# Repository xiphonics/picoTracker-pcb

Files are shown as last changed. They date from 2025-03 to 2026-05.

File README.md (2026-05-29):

# PCB for PicoTracker
All data in order to fabricate the PCB for the [picoTracker](https://github.com/xiphonics/picoTracker)

Buy the official kit at [xiphonics store](https://xiphonics.com/products/picotracker-pcb-kit)
# Trademark Notice

This repository contains the open-source hardware design files for the picoTracker project.

The hardware design files are released under the CC0 1.0 Universal license and may be used, modified, manufactured, and sold without restriction.

However, the **picoTracker** name, logos, product branding, and associated trademarks are **not** covered by the CC0 license and are not licensed for use by third parties.

You may manufacture and sell hardware derived from these design files, but you may not market, advertise, label, or otherwise represent such products using the "picoTracker" name or branding without prior written permission from Xiphonics.

Products manufactured from these files must be sold under a different product name and must not imply endorsement by, affiliation with, or origin from Xiphonics.

To facilitate this separation, the manufacturing files distributed through this repository intentionally omit picoTracker branding elements.

Use of the picoTracker name in connection with unauthorized derivative hardware may constitute trademark infringement and unfair competition.

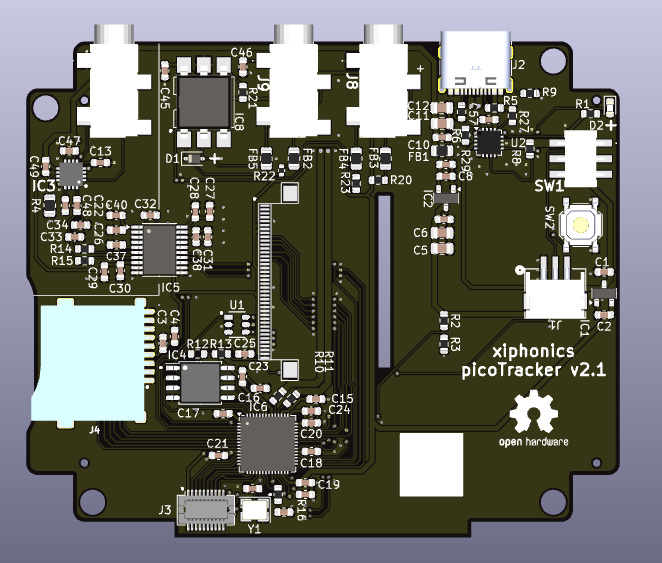
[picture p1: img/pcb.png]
picoTrakerPCB


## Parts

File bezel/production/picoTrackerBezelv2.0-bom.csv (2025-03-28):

Designator | Footprint | Quantity | Value | LCSC Part #
H1, H2, H3, H4 | MountingHole_3.2mm_M3 | 4 | MountingHole

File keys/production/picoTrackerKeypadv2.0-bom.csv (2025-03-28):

Designator | Footprint | Quantity | Value | LCSC Part #
H1, H2, H3 | MountingHole_3.2mm_M3 | 3 | MountingHole
J1 | Hirose_DF12_DF12E3.0-20DP-0.5V_2x10_P0.50mm_Vertical | 1 | DF12NC(5.0)-20DP-0.5V(51) | C3650665
SW10 | Cherry-MX-Low-Profile-kailh | 1 | NAV | C400229
SW11 | Cherry-MX-Low-Profile-kailh | 1 | PLAY | C400229
SW3 | Cherry-MX-Low-Profile-kailh | 1 | LEFT | C400229
SW4 | Cherry-MX-Low-Profile-kailh | 1 | DOWN | C400229
SW5 | Cherry-MX-Low-Profile-kailh | 1 | RIGHT | C400229
SW6 | Cherry-MX-Low-Profile-kailh | 1 | UP | C400229
SW7 | Cherry-MX-Low-Profile-kailh | 1 | ALT | C400229
SW8 | Cherry-MX-Low-Profile-kailh | 1 | EDIT | C400229
SW9 | Cherry-MX-Low-Profile-kailh | 1 | ENTER | C400229

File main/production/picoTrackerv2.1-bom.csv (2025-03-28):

Designator | Footprint | Quantity | Value | LCSC Part #
C1, C2, C27, C29, C3, C31, C40 | 0603 | 7 | 10uF | C19702
C10, C22, C32, C37, C48, C7, C8, C9 | 0603 | 8 | 2.2uF | C23630
C11, C12, C5, C6 | 0805 | 4 | 47uF | C16780
C13, C23, C24, C47, C49, C57 | 0603 | 6 | 1uF | C15849
C14, C15, C16, C17, C18, C19, C20, C21, C25, C26, C28, C30, C38, C4, C45, C46 | 0603 | 16 | 100nF | C14663
C33, C34 | 0603 | 2 | 2.2nF | C1604
C35, C36 | 0603 | 2 | 20pF | C1648
D1 | D_SOD-323 | 1 | 1N4148WS | C2128
D2 | 0603 | 1 | LED | C2286
FB1, FB2, FB3, FB4, FB5 | 0805 | 5 | 600@100MHz | C1017
H1, H2, H3, H4 | MountingHole_3.2mm_M3 | 4 | MountingHole
IC1, IC2 | SOT-23 | 2 | XC6206P332MR | C5446
IC3 | QFN50P300X300X100-17N-D | 1 | TPA6139A2RGTR | C2868391
IC4 | SOIC-8_5.23x5.23mm_P1.27mm | 1 | W25Q128JVS | C97521
IC5 | TSSOP-20_4.4x6.5mm_P0.65mm | 1 | PCM5102A | C107671
IC6 | QFN-56-1EP_7x7mm_P0.4mm_EP3.2x3.2mm | 1 | RP2040 | C2040
IC8 | SMDIP-6_W9.53mm | 1 | H11L1 | C78589
J1 | CONN_S3B-ZR-SM4A-TFLFSN_JST | 1 | Conn_01x03 | C72591
J10 | FPC_40-flap | 1 | FPC-05FB-40PH20 | C2856837
J2 | USB_C_Receptacle_G-Switch_GT-USB-7010ASV | 1 | USB_C_Receptacle_USB2.0 | C2988369
J3 | Hirose_DF12_DF12C3.0-20DS-0.5V_2x10_P0.50mm_Vertical | 1 | Conn_02x10_Counter_Clockwise | C3645324
J4 | Xunpu_TF-115_microSD | 1 | Micro_SD_Card | C720505
J5 | PJ327C4A | 1 | Headphones | C145813
J8 | PJ327C4A | 1 | MIDI Out | C145813
J9 | PJ327C4A | 1 | MIDI In | C145813
R1, R13, R16, R27, R8 | 0603 | 5 | 1k | C21190
R10, R11 | 0603 | 2 | 27 | C25190
R12 | 0603 | 1 | DNF
R14, R15 | 0603 | 2 | 470 | C23179
R2, R3 | 0603 | 2 | 100k | C25803
R20 | 0603 | 1 | 33 | C23140
R21 | 0603 | 1 | 270 | C22966
R22 | 0402 | 1 | 220 | C1111
R23 | 0603 | 1 | 10 | C22859
R29 | 0603 | 1 | 560 | C23204
R4 | 0805 | 1 | 82k | C17840
R5, R6 | 0603 | 2 | 5k1 | C23186
R9 | 0603 | 1 | 1M | C22935
SW1 | MS22D28G020 | 1 | MS-22D28-G020 | C963205
SW2 | SW_Push_1P1T_XKB_TS-1187A | 1 | SW_SPST | C318884
U1 | SOT23-6_DIO | 1 | AP2502KTR-G1 | C460349
U2 | VQFN-16-1EP_3x3mm_P0.5mm_EP1.6x1.6mm | 1 | BQ24074RGT | C54313
Y1 | Crystal_SMD_3225-4Pin_3.2x2.5mm | 1 | 12MHz 20pF ±10ppm | C9002

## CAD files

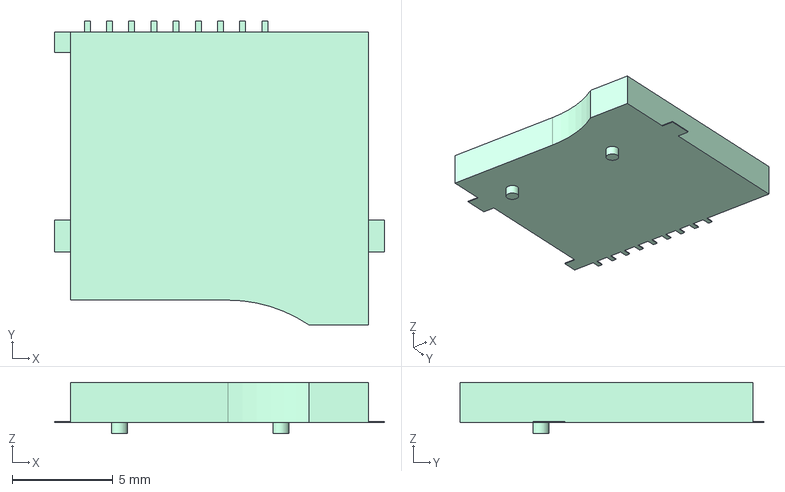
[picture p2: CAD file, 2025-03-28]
step/sdscard.step
16.4 x 15.1 x 2.55 mm

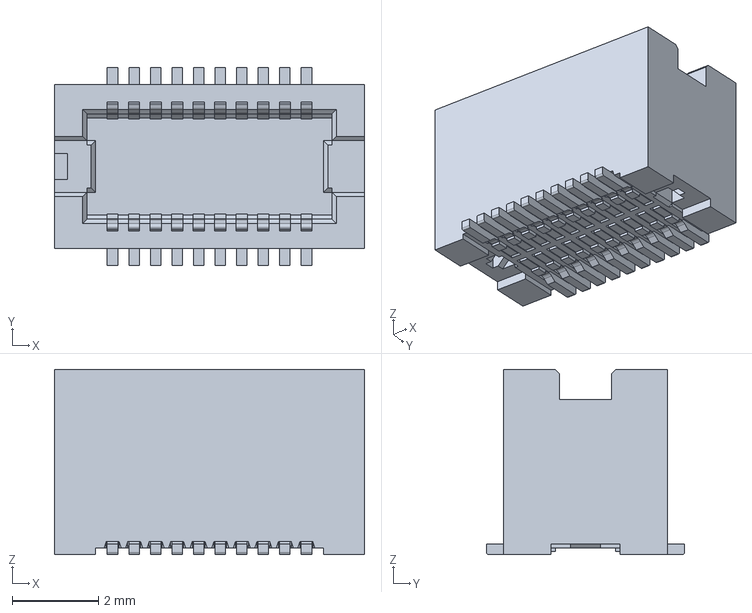
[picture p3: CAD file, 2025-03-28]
step/DF12NC(5.0)-20DP.stp
7.20 x 4.60 x 4.30 mm

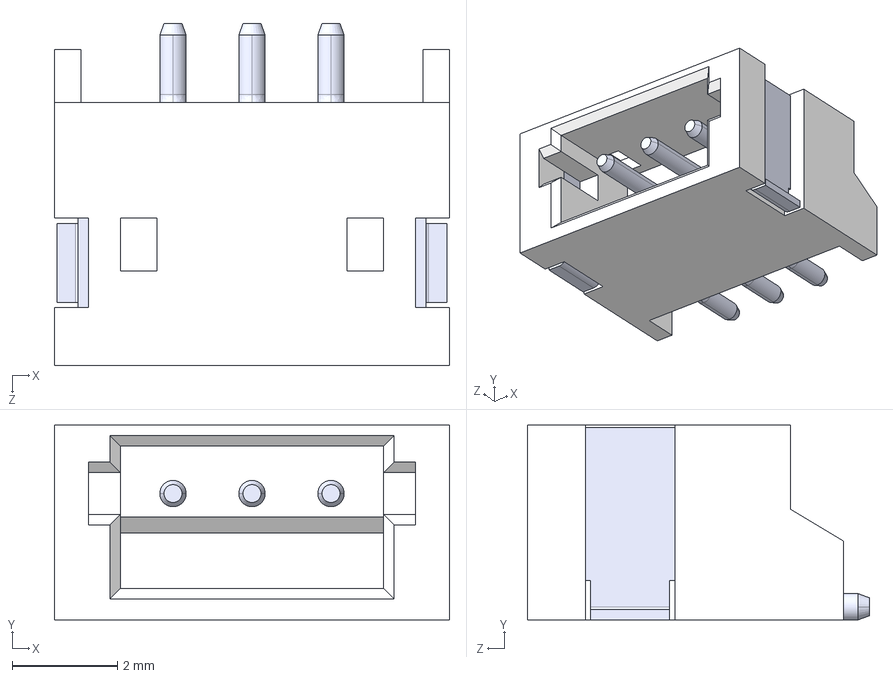
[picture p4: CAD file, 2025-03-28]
step/S3B-ZR-SM4A-TF.step
7.50 x 3.70 x 6.50 mm

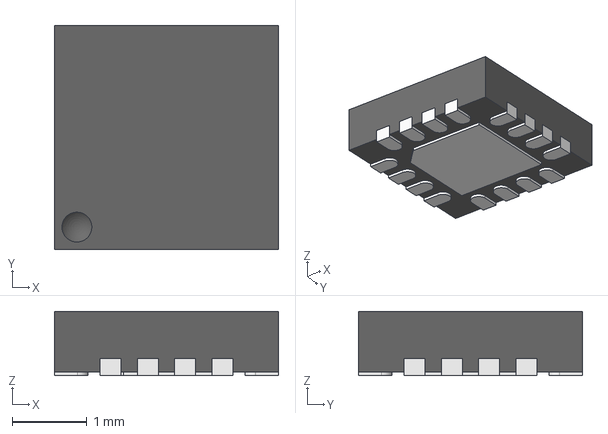
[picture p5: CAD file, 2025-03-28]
step/QFN-16 (3x3).stp
3.00 x 3.00 x 0.86 mm
QFN-16 (3x3) Part1
QFN-16 (3x3) Part2 x 16

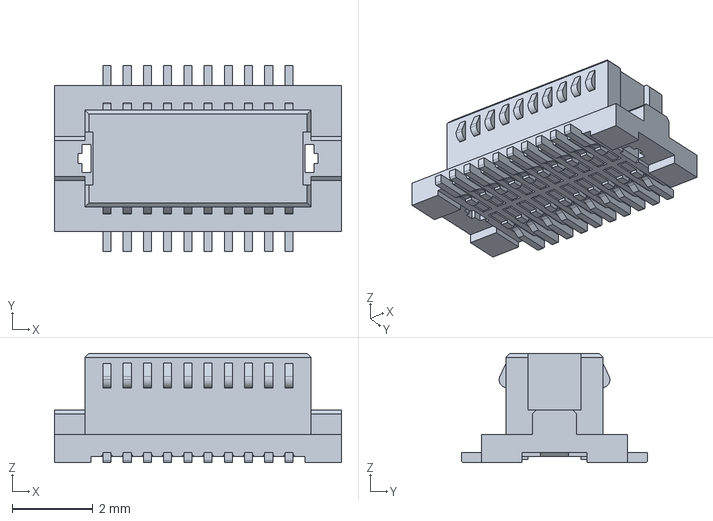
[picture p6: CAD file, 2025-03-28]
step/DF12NC-20DS.stp
7.10 x 4.60 x 2.70 mm

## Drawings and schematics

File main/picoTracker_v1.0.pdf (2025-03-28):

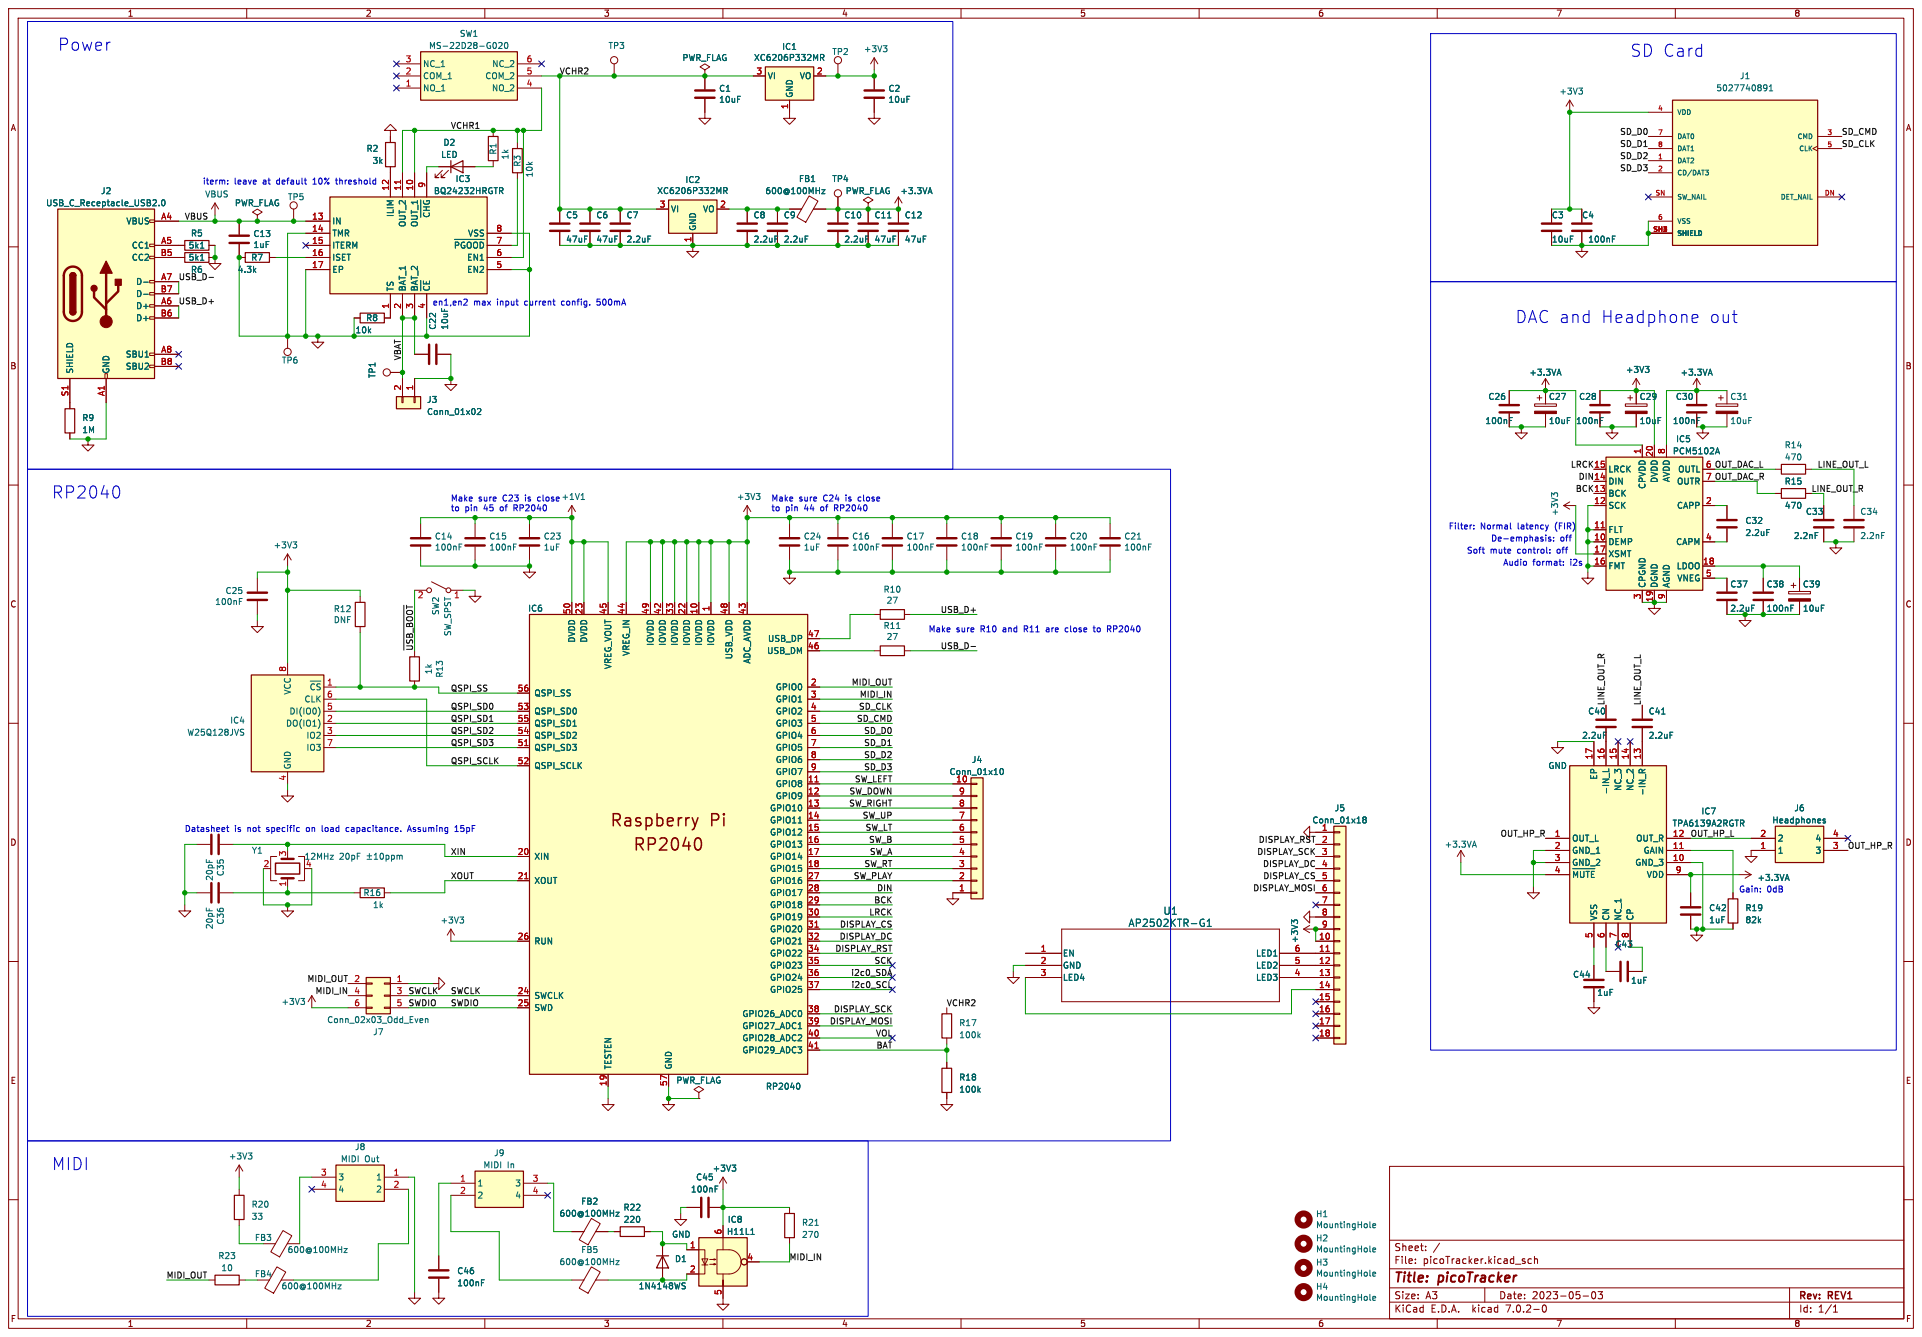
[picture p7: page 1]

iterm: leave at default 10% threshold Power

SD_CMD DAC and Headphone out

3 ~{CE} 4 EN2 5 EN1 6 ~{PGOOD}7 VSS 8 ~{CHG}9 C22 10uF R2

3 ~{CE} 4 EN2 5 EN1 6 ~{PGOOD}7 VSS 8 ~{CHG}9

1 DEMP 10 FLT 11 SCK 12 BCK 13 DIN 14

Make sure C23 is close

1 IOVDD 10 GPIO8 11 GPIO9 12 GPIO10 13 GPIO11 14 GPIO12 15 GPIO13 16 GPIO14 17 GPIO15 18 TESTEN 19 GPIO0 2 XIN 20 XOUT 21 IOVDD 22 DVDD 23 SWCLK 24 SWD 25 RUN 26 GPIO16 27 GPIO17 28 GPIO18 29 GPIO1 3 GPIO19 30 GPIO20 31 GPIO21 32 IOVDD 33 GPIO22 34 GPIO23 35 GPIO24 36 GPIO25 37 GPIO26_ADC0 38 GPIO27_ADC1 39 GPIO2 4 GPIO28_ADC2 40 GPIO29_ADC3 41 IOVDD 42 ADC_AVDD 43 VREG_IN 44 VREG_VOUT 45 USB_DM 46 USB_DP 47 USB_VDD 48 IOVDD 49 GPIO3 5 DVDD 50 QSPI_SD3 51 QSPI_SCLK 52 QSPI_SD0 53 QSPI_SD2 54 QSPI_SD1 55 QSPI_SS 56 GND 57 GPIO4 6 GPIO5 7 GPIO6 8 GPIO7 9

1 IOVDD 10 GPIO8 11 GPIO9 12 GPIO10 13 GPIO11 14 GPIO12 15 GPIO13 16 GPIO14 17 GPIO15 18 TESTEN 19 GPIO0 2 XIN 20 XOUT 21 IOVDD 22 DVDD 23 SWCLK 24 SWD 25 RUN 26 GPIO16 27 GPIO17 28 GPIO18 29 GPIO1 3 GPIO19 30 GPIO20 31 GPIO21 32 IOVDD 33 GPIO22 34 GPIO23 35 GPIO24 36 GPIO25 37 GPIO26_ADC0 38 GPIO27_ADC1 39 GPIO2 4 GPIO28_ADC2 40 GPIO29_ADC3 41 IOVDD 42 ADC_AVDD 43 VREG_IN 44 VREG_VOUT 45 USB_DM 46 USB_DP 47 USB_VDD 48 IOVDD 49 GPIO3 5 DVDD 50 QSPI_SD3 51 QSPI_SCLK 52 QSPI_SD0 53 QSPI_SD2 54 QSPI_SD1 55 QSPI_SS 56 GND 57 GPIO4 6 GPIO5 7 GPIO6 8 GPIO7 9 PWR_FLAG

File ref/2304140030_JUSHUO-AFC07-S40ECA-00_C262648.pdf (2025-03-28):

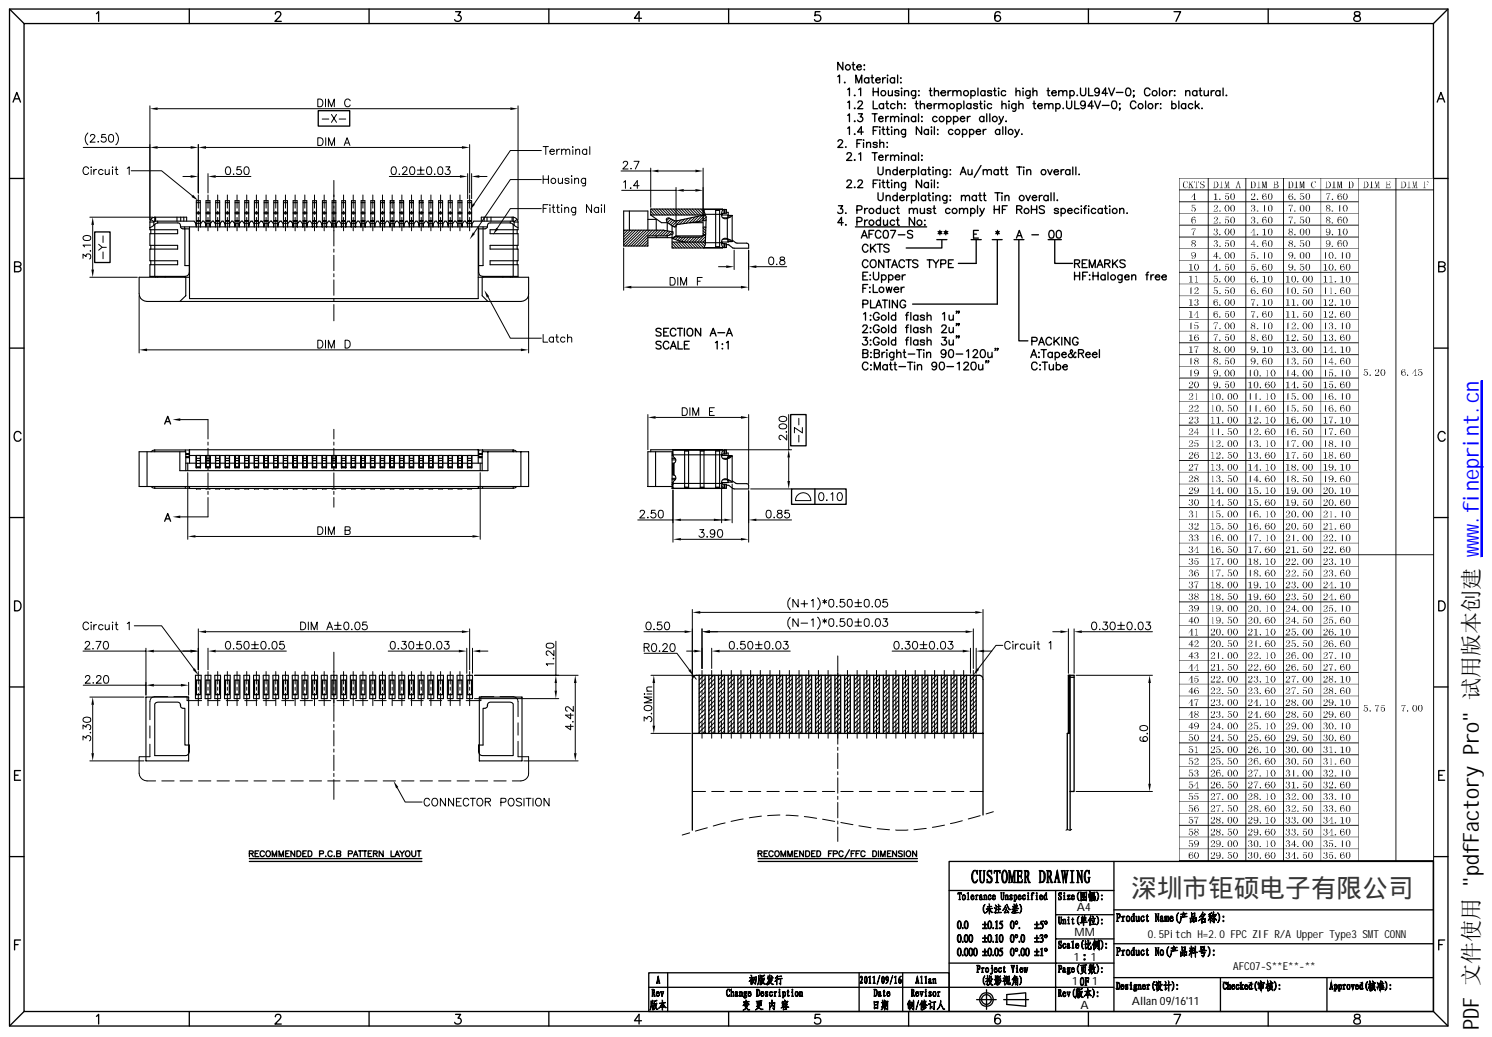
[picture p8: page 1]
AFC07-S**E**-**; Allan 09/16'11

PDF 文件使用 "pdfFactory Pro" 试用版本创建 www.fineprint.cn

0.5Pitch H=2.0 FPC ZIF R/A Upper Type3 SMT CONN

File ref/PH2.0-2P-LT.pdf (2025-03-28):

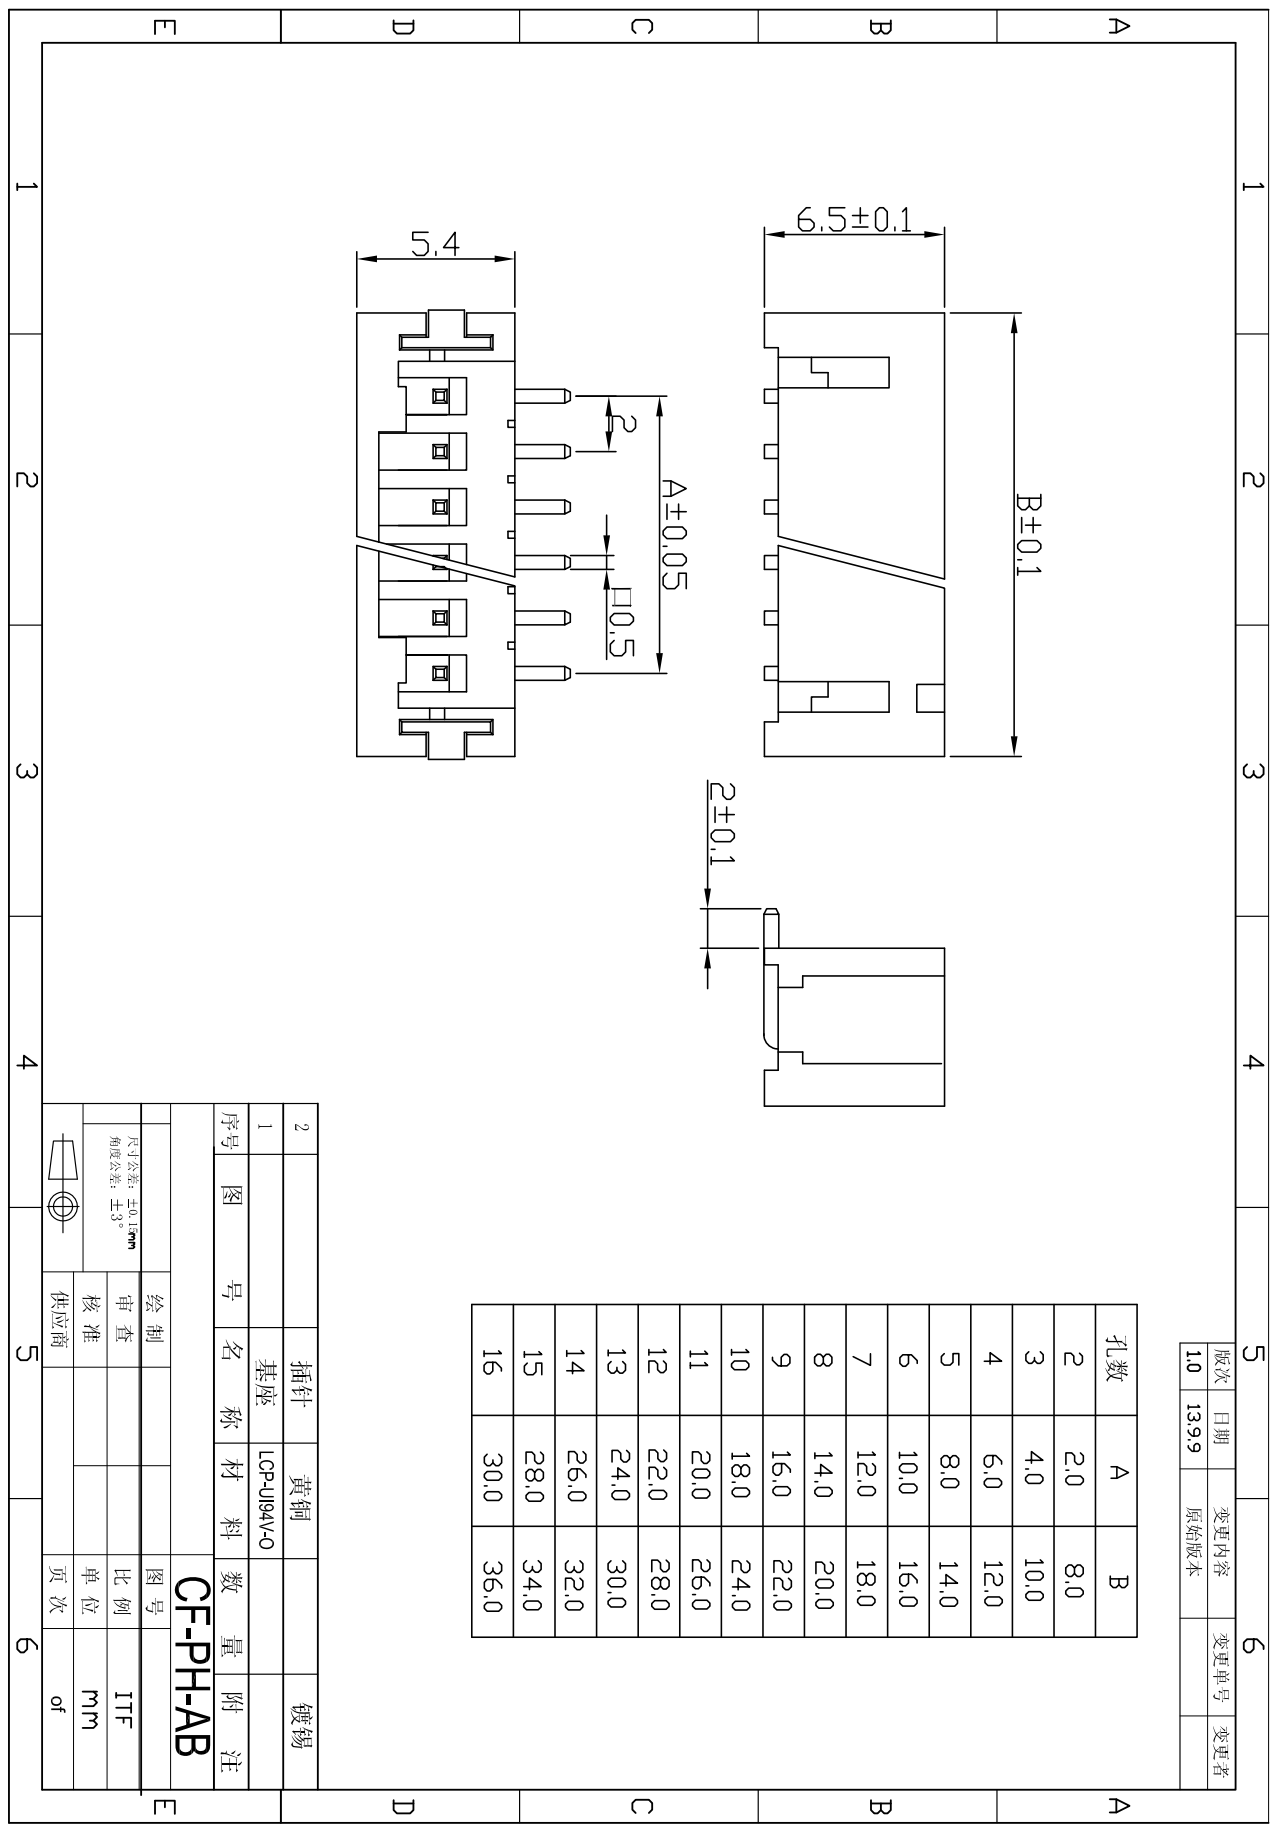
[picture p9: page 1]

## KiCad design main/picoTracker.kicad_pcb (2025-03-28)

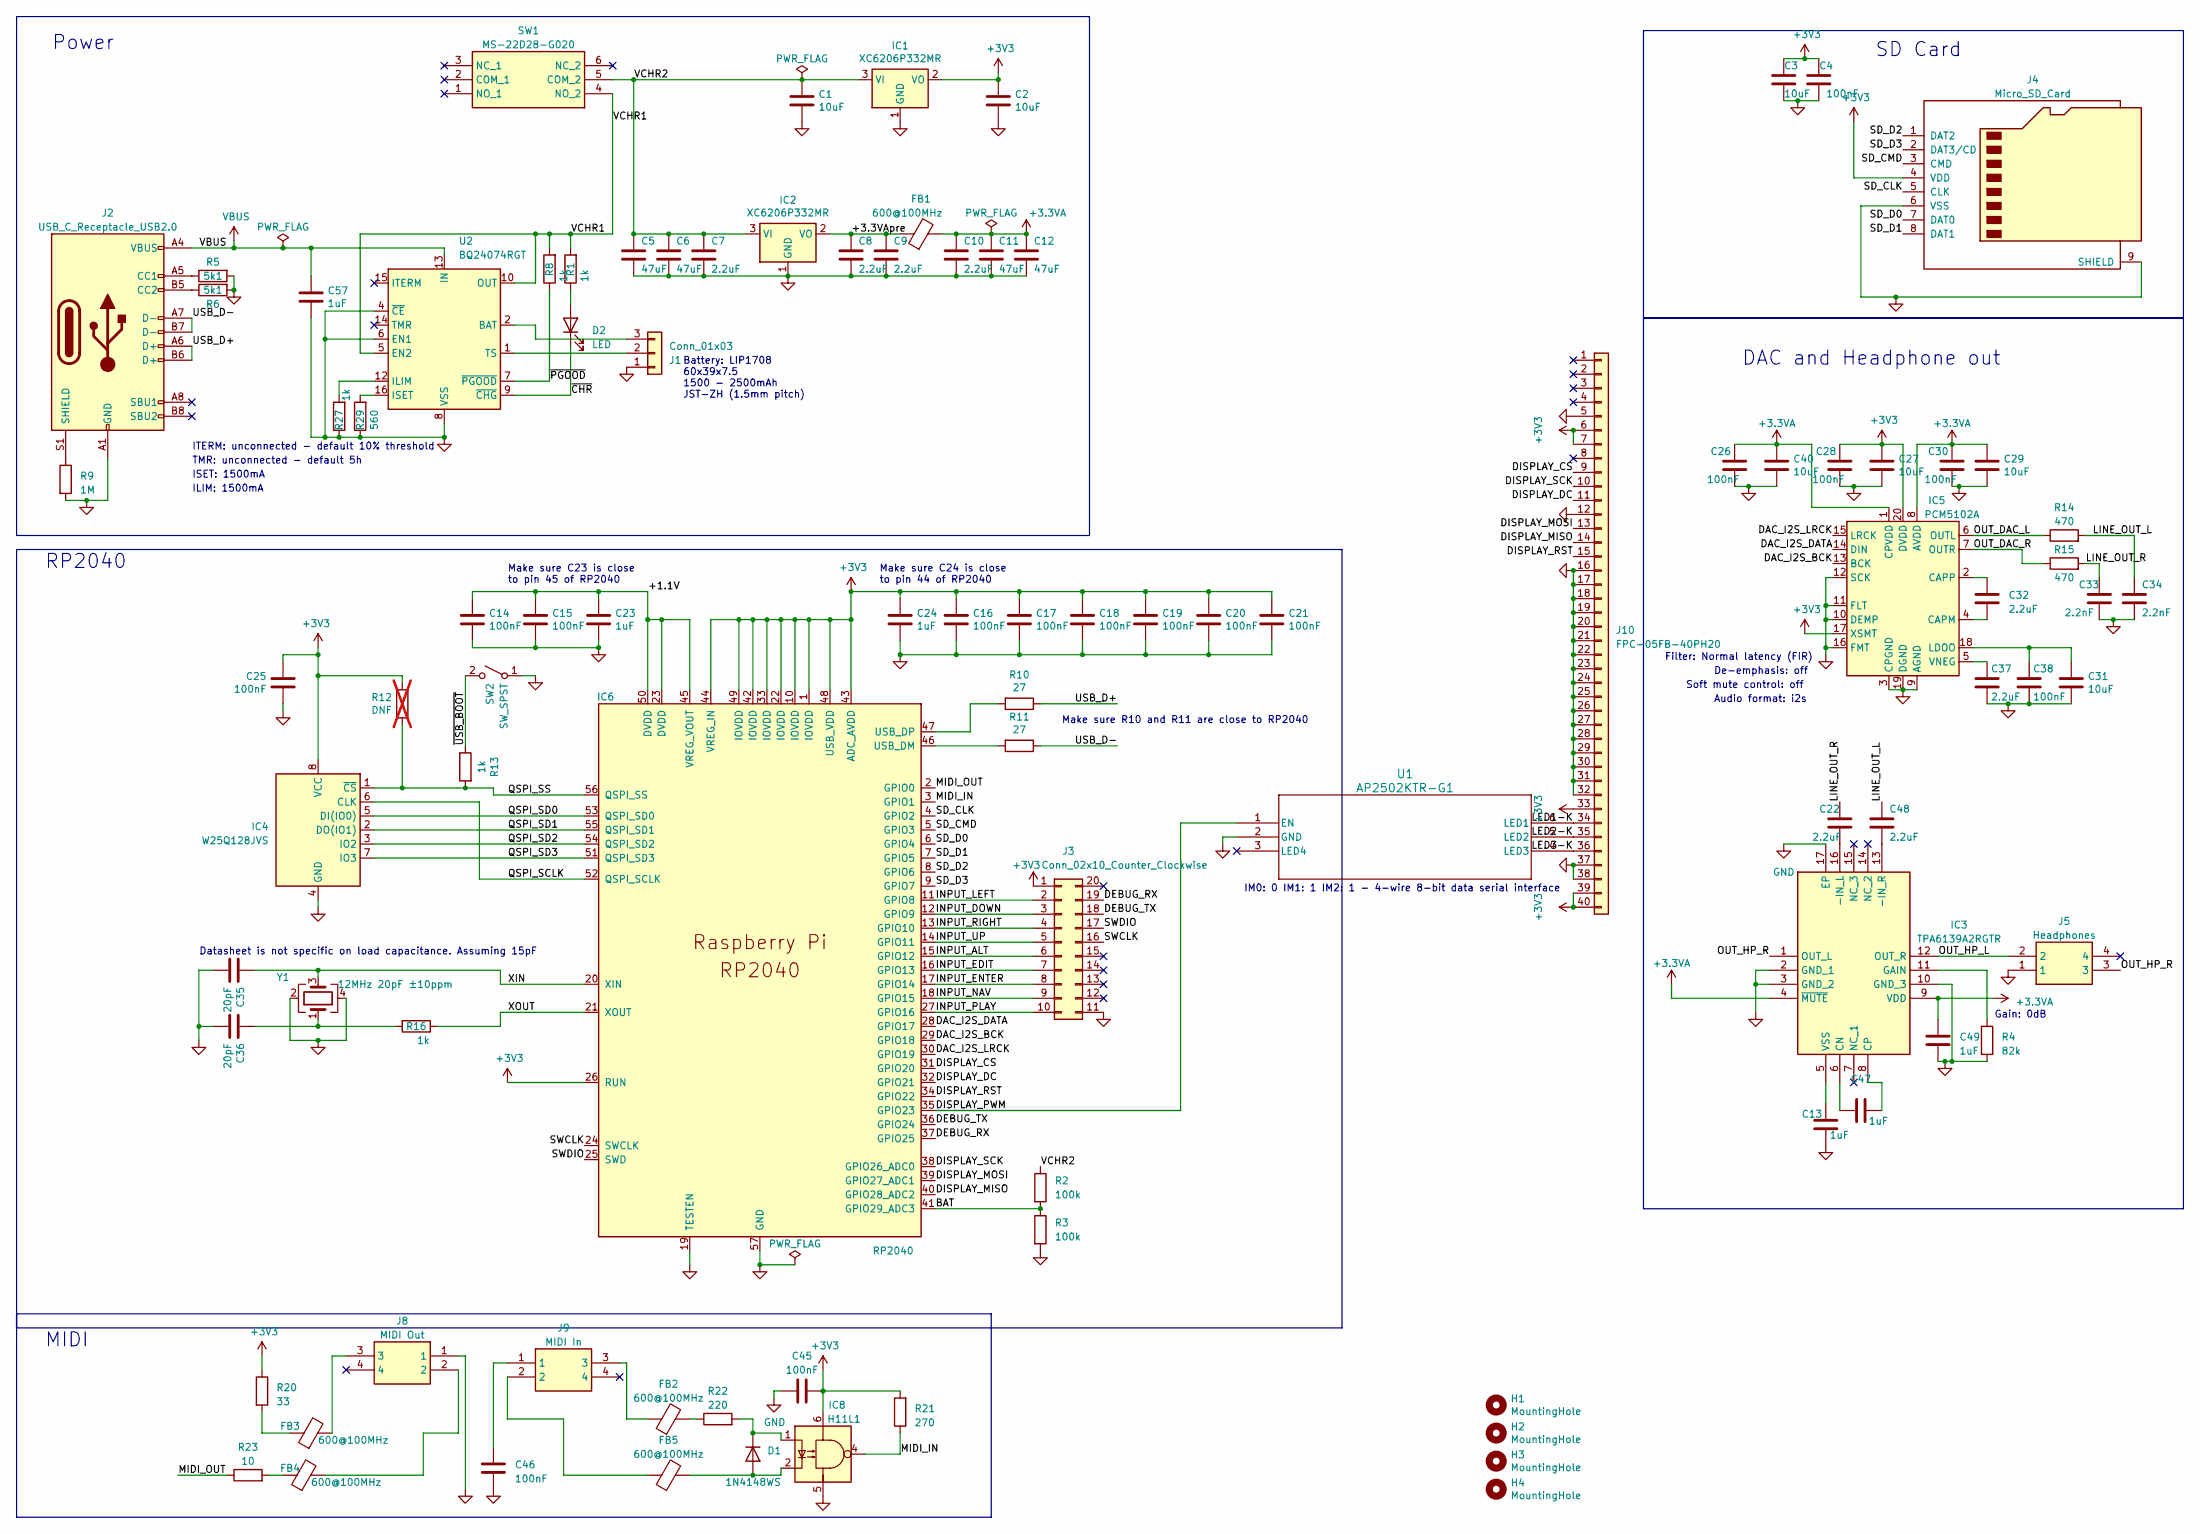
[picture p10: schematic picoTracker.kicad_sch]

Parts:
C1, C2, C3, C27, C29, C31, C40: 10uF; C_0603_1608Metric; LCSC C19702
C4, C14, C15, C16, C17, C18, C19, C20, C21, C25, C26, C28, C30, C38, C45, C46: 100nF; C_0603_1608Metric; LCSC C14663
C5, C6, C11, C12: 47uF; C_0805_2012Metric; LCSC C16780
C7, C8, C9, C10, C22, C32, C37, C48: 2.2uF; C_0603_1608Metric; LCSC C23630
C13, C23, C24, C47, C49, C57: 1uF; C_0603_1608Metric; LCSC C15849
C33, C34: 2.2nF; C_0603_1608Metric; LCSC C1604
C35, C36: 20pF; C_0603_1608Metric; LCSC C1648
D1: 1N4148WS; D_SOD-323; LCSC C2128
D2: LED; LED_0603_1608Metric; LCSC C2286
FB1, FB2, FB3, FB4, FB5: 600@100MHz; R_0805_2012Metric; LCSC C1017
H1, H2, H3, H4: MountingHole; MountingHole_3.2mm_M3
IC1, IC2: XC6206P332MR; SOT-23; LCSC C5446
IC3: TPA6139A2RGTR; QFN50P300X300X100-17N-D; Mouser Part Number 595-TPA6139A2RGTR
IC4: W25Q128JVS; SOIC-8_5.23x5.23mm_P1.27mm; LCSC C97521
IC5: PCM5102A; TSSOP-20_4.4x6.5mm_P0.65mm; LCSC C107671
IC6: RP2040; QFN-56-1EP_7x7mm_P0.4mm_EP3.2x3.2mm; LCSC C2040
IC8: H11L1; SMDIP-6_W9.53mm; LCSC C78589
J1: Conn_01x03; CONN_S3B-ZR-SM4A-TFLFSN_JST; LCSC C72591
J2: USB_C_Receptacle_USB2.0; USB_C_Receptacle_G-Switch_GT-USB-7010ASV; LCSC C2988369
J3: Conn_02x10_Counter_Clockwise; Hirose_DF12_DF12C3.0-20DS-0.5V_2x10_P0.50mm_Vertical; LCSC C3645324
J4: Micro_SD_Card; Xunpu_TF-115_microSD; LCSC C720505
J5: Headphones; PJ327C4A; Manufacturer_Part_Number PJ-327C-4A; LCSC C145813
J8: MIDI Out; PJ327C4A; Manufacturer_Part_Number PJ-327C-4A; LCSC C145813
J9: MIDI In; PJ327C4A; Manufacturer_Part_Number PJ-327C-4A; LCSC C145813
J10: FPC-05FB-40PH20; FPC_40-flap; LCSC C2856837
R1, R8, R13, R16, R27: 1k; R_0603_1608Metric; LCSC C21190
R2, R3: 100k; R_0603_1608Metric; LCSC C25803
R4: 82k; R_0805_2012Metric; LCSC C17840
R5, R6: 5k1; R_0603_1608Metric; LCSC C23186
R9: 1M; R_0603_1608Metric; LCSC C22935
R10, R11: 27; R_0603_1608Metric; LCSC C25190
R12: DNF; R_0603_1608Metric; not fitted
R14, R15: 470; R_0603_1608Metric; LCSC C23179
R20: 33; R_0603_1608Metric; LCSC C23140
R21: 270; R_0603_1608Metric; LCSC C22966
R22: 220; R_0402_1005Metric; LCSC C1111
R23: 10; R_0603_1608Metric; LCSC C22859
R29: 560; R_0603_1608Metric; LCSC C23204
SW1: MS-22D28-G020; MS22D28G020; Manufacturer_Part_Number MS-22D28-G020; LCSC C963205
SW2: SW_SPST; SW_Push_1P1T_XKB_TS-1187A; LCSC C318884
U1: AP2502KTR-G1; SOT23-6_DIO; LCSC C460349
U2: BQ24074RGT; VQFN-16-1EP_3x3mm_P0.5mm_EP1.6x1.6mm; LCSC C54313
Y1: 12MHz 20pF ±10ppm; Crystal_SMD_3225-4Pin_3.2x2.5mm; LCSC C9002

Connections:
+3.3VA: C10.1, C11.1, C12.1, C26.1, C29.1, C30.1, C40.1, C49.1, FB1.2, IC3.4 (~MUTE), IC3.9 (VDD), IC5.1 (CPVDD), IC5.8 (AVDD)
+3V3: C2.1, C3.1, C4.1, C16.1, C17.1, C18.1, C19.1, C20.1, C21.1, C24.1, C25.1, C27.1, C28.1, C45.2, IC1.2 (VO), IC4.8 (VCC), IC5.17 (XSMT), IC5.20 (DVDD), IC6.1 (IOVDD), IC6.10 (IOVDD), IC6.22 (IOVDD), IC6.26 (RUN), IC6.33 (IOVDD), IC6.42 (IOVDD), IC6.43 (ADC_AVDD), IC6.44 (VREG_IN), IC6.48 (USB_VDD), IC6.49 (IOVDD), IC8.6, J3.1, J4.4 (VDD), J10.6, J10.7, J10.33, J10.39, J10.40, R12.1, R20.1, R21.2
/+1.1V: C14.1, C15.1, C23.1, IC6.23 (DVDD), IC6.45 (VREG_VOUT), IC6.50 (DVDD)
/+3.3VApre: C8.1, C9.1, FB1.1, IC2.2 (VO)
/BAT: IC6.41 (GPIO29_ADC3), R2.2, R3.1
/DAC_I2S_BCK: IC5.13 (BCK), IC6.29 (GPIO18)
/DAC_I2S_DATA: IC5.14 (DIN), IC6.28 (GPIO17)
/DAC_I2S_LRCK: IC5.15 (LRCK), IC6.30 (GPIO19)
/DEBUG_RX: IC6.37 (GPIO25), J3.19
/DEBUG_TX: IC6.36 (GPIO24), J3.18
/DISPLAY_CS: IC6.31 (GPIO20), J10.9
/DISPLAY_DC: IC6.32 (GPIO21), J10.11
/DISPLAY_MISO: IC6.40 (GPIO28_ADC2), J10.14
/DISPLAY_MOSI: IC6.39 (GPIO27_ADC1), J10.13
/DISPLAY_PWM: IC6.35 (GPIO23), U1.1 (EN)
/DISPLAY_RST: IC6.34 (GPIO22), J10.15
/DISPLAY_SCK: IC6.38 (GPIO26_ADC0), J10.10
/INPUT_ALT: IC6.15 (GPIO12), J3.6
/INPUT_DOWN: IC6.12 (GPIO9), J3.3
/INPUT_EDIT: IC6.16 (GPIO13), J3.7
/INPUT_ENTER: IC6.17 (GPIO14), J3.8
/INPUT_LEFT: IC6.11 (GPIO8), J3.2
/INPUT_NAV: IC6.18 (GPIO15), J3.9
/INPUT_PLAY: IC6.27 (GPIO16), J3.10
/INPUT_RIGHT: IC6.13 (GPIO10), J3.4
/INPUT_UP: IC6.14 (GPIO11), J3.5
/LED1-K: J10.34, U1.6 (LED1)
/LED2-K: J10.35, U1.5 (LED2)
/LED3-K: J10.36, U1.4 (LED3)
/LINE_OUT_L: C34.1, C48.1, R14.2
/LINE_OUT_R: C22.1, C33.1, R15.2
/MIDI_IN: IC6.3 (GPIO1), IC8.4, R21.1
/MIDI_OUT: IC6.2 (GPIO0), R23.1
/OUT_DAC_L: IC5.6 (OUTL), R14.1
/OUT_DAC_R: IC5.7 (OUTR), R15.1
/OUT_HP_L: IC3.12 (OUT_R), J5.2
/OUT_HP_R: IC3.1 (OUT_L), J5.3
/QSPI_SCLK: IC4.6 (CLK), IC6.52 (QSPI_SCLK)
/QSPI_SD0: IC4.5 (DI(IO0)), IC6.53 (QSPI_SD0)
/QSPI_SD1: IC4.2 (DO(IO1)), IC6.55 (QSPI_SD1)
/QSPI_SD2: IC4.3 (IO2), IC6.54 (QSPI_SD2)
/QSPI_SD3: IC4.7 (IO3), IC6.51 (QSPI_SD3)
/QSPI_SS: IC4.1 (~CS), IC6.56 (QSPI_SS), R12.2, R13.2
/SD_CLK: IC6.4 (GPIO2), J4.5 (CLK)
/SD_CMD: IC6.5 (GPIO3), J4.3 (CMD)
/SD_D0: IC6.6 (GPIO4), J4.7 (DAT0)
/SD_D1: IC6.7 (GPIO5), J4.8 (DAT1)
/SD_D2: IC6.8 (GPIO6), J4.1 (DAT2)
/SD_D3: IC6.9 (GPIO7), J4.2 (DAT3/CD)
/SWCLK: IC6.24 (SWCLK), J3.16
/SWDIO: IC6.25 (SWD), J3.17
/USB_D+: J2.A6 (D+), J2.B6 (D+), R10.1
/USB_D-: J2.A7 (D-), J2.B7 (D-), R11.1
/VCHR1: R1.2, R8.2, SW1.4 (NO_2), U2.5 (EN2), U2.10 (OUT), U2.11 (OUT)
/VCHR2: C1.1, C5.1, C6.1, C7.1, IC1.3 (VI), IC2.3 (VI), R2.1, SW1.5 (COM_2)
/XIN: C35.1, IC6.20 (XIN), Y1.3
/XOUT: IC6.21 (XOUT), R16.1
/~CHR: D2.1 (K), U2.9 (~CHG)
/~PGOOD: R8.1, U2.7 (~PGOOD)
/~USB_BOOT: R13.1, SW2.2 (B)
GND: C1.2, C2.2, C3.2, C4.2, C5.2, C6.2, C7.2, C8.2, C9.2, C10.2, C11.2, C12.2, C13.2, C14.2, C15.2, C16.2, C17.2, C18.2, C19.2, C20.2, C21.2, C23.2, C24.2, C25.2, C26.2, C27.2, C28.2, C29.2, C30.2, C31.2, C33.2, C34.2, C35.2, C36.2, C37.2, C38.2, C40.2, C45.1, C46.2, C49.2, C57.2, IC1.1 (GND), IC2.1 (GND), IC3.2 (GND_1), IC3.3 (GND_2), IC3.10 (GND_3), IC3.17 (EP), IC4.4 (GND), IC5.3 (CPGND), IC5.9 (AGND), IC5.10 (DEMP), IC5.11 (FLT), IC5.12 (SCK), IC5.16 (FMT), IC5.19 (DGND), IC6.19 (TESTEN), IC6.57 (GND), IC8.5, J1.1, J2.A1 (GND), J2.A12 (GND), J2.B1 (GND), J2.B12 (GND), J3.11, J4.6 (VSS), J4.9 (SHIELD), J5.1, J8.1, J10.5, J10.12, J10.16, J10.17, J10.18, J10.19, J10.20, J10.21, J10.22, J10.23, J10.24, J10.25, J10.26, J10.27, J10.28, J10.29, J10.30, J10.31, J10.32, J10.37, J10.38, R3.2, R4.2, R5.2, R6.2, R9.2, R27.1, R29.1, SW2.1 (A), U1.2 (GND), U2.4 (~CE), U2.6 (EN1), U2.8 (VSS), U2.17 (VSS), Y1.2, Y1.4
unnamed: C36.1, R16.2, Y1.1
unnamed: C46.1, J9.1
unnamed: D1.2 (A), FB5.2, IC8.2
unnamed: D1.1 (K), IC8.1, R22.2
unnamed: D2.2 (A), R1.1
unnamed: FB2.1, J9.3
unnamed: FB2.2, R22.1
unnamed: FB3.1, R20.2
unnamed: FB3.2, J8.3
unnamed: FB4.1, R23.2
unnamed: FB4.2, J8.2
unnamed: FB5.1, J9.2
unnamed: C22.2, IC3.16 (-IN_L)
unnamed: C48.2, IC3.13 (-IN_R)
unnamed: C47.1, IC3.6 (CN)
unnamed: C47.2, IC3.8 (CP)
unnamed: IC3.11 (GAIN), R4.1
unnamed: C13.1, IC3.5 (VSS)
unnamed: C32.2, IC5.4 (CAPM)
unnamed: C32.1, IC5.2 (CAPP)
unnamed: C31.1, C38.1, IC5.18 (LDOO)
unnamed: C37.1, IC5.5 (VNEG)
unnamed: IC6.46 (USB_DM), R11.2
unnamed: IC6.47 (USB_DP), R10.2
unnamed: J1.2, U2.1 (TS)
unnamed: J1.3, U2.2 (BAT), U2.3 (BAT)
unnamed: J2.A5 (CC1), R5.1
unnamed: J2.B5 (CC2), R6.1
unnamed: J2.S1 (SHIELD), R9.1
unnamed: R27.2, U2.12 (ILIM)
unnamed: R29.2, U2.16 (ISET)
VBUS: C57.1, J2.A4 (VBUS), J2.A9 (VBUS), J2.B4 (VBUS), J2.B9 (VBUS), U2.13 (IN)

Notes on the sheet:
DAC and Headphone out
Gain: 0dB
ITERM: unconnected - default 10% threshold
SD Card
Battery: LIP1708 60x39x7.5 1500 - 2500mAh JST-ZH (1.5mm pitch)
Power
RP2040
Filter: Normal latency (FIR)
IM0: 0 IM1: 1 IM2: 1 - 4-wire 8-bit data serial interface
Datasheet is not specific on load capacitance. Assuming 15pF
ILIM: 1500mA
ISET: 1500mA
TMR: unconnected - default 5h
Make sure C23 is close to pin 45 of RP2040
Soft mute control: off
Make sure R10 and R11 are close to RP2040
De-emphasis: off
MIDI
Audio format: i2s
Make sure C24 is close to pin 44 of RP2040

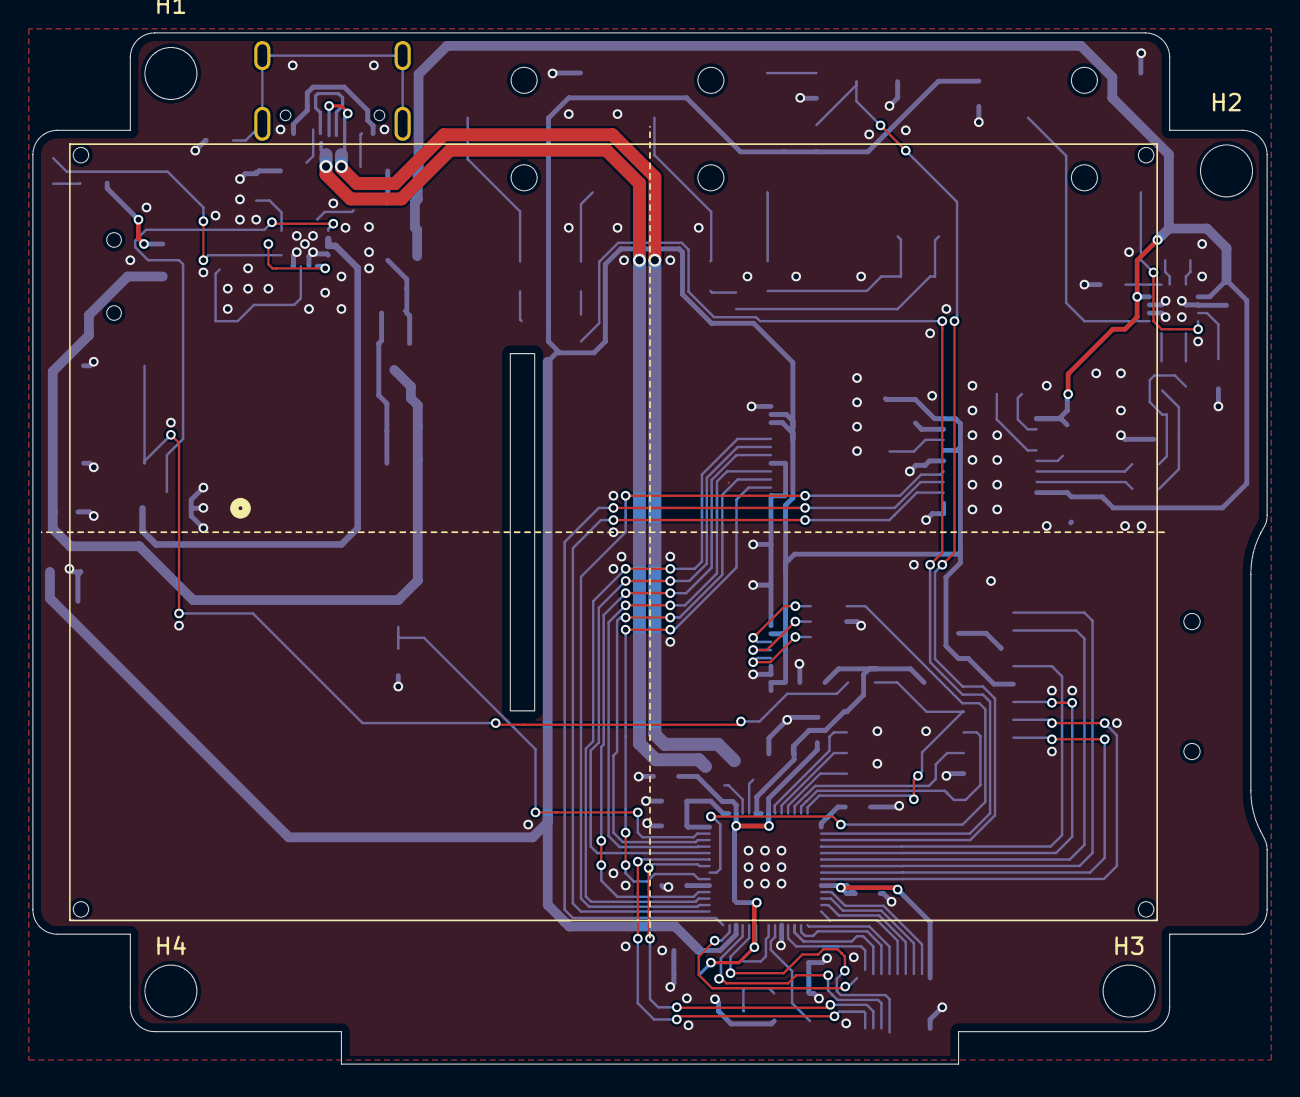
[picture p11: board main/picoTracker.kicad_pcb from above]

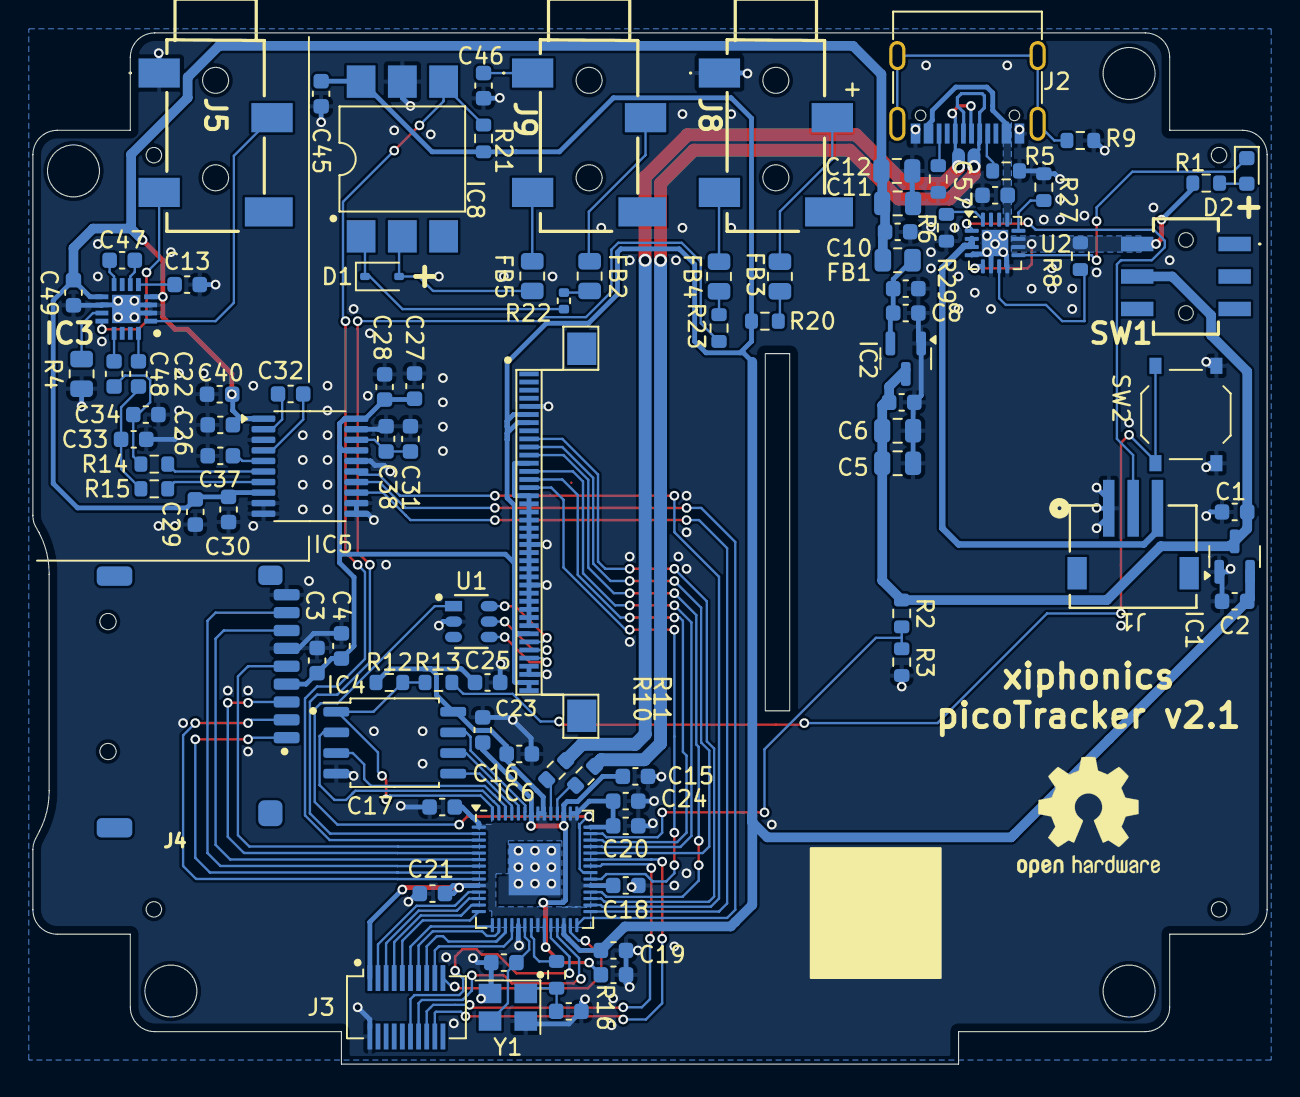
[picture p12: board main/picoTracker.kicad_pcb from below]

Board: 2 copper layers, 76.0 x 63.5 mm, 97 parts (93 on the bottom side), 93 nets.

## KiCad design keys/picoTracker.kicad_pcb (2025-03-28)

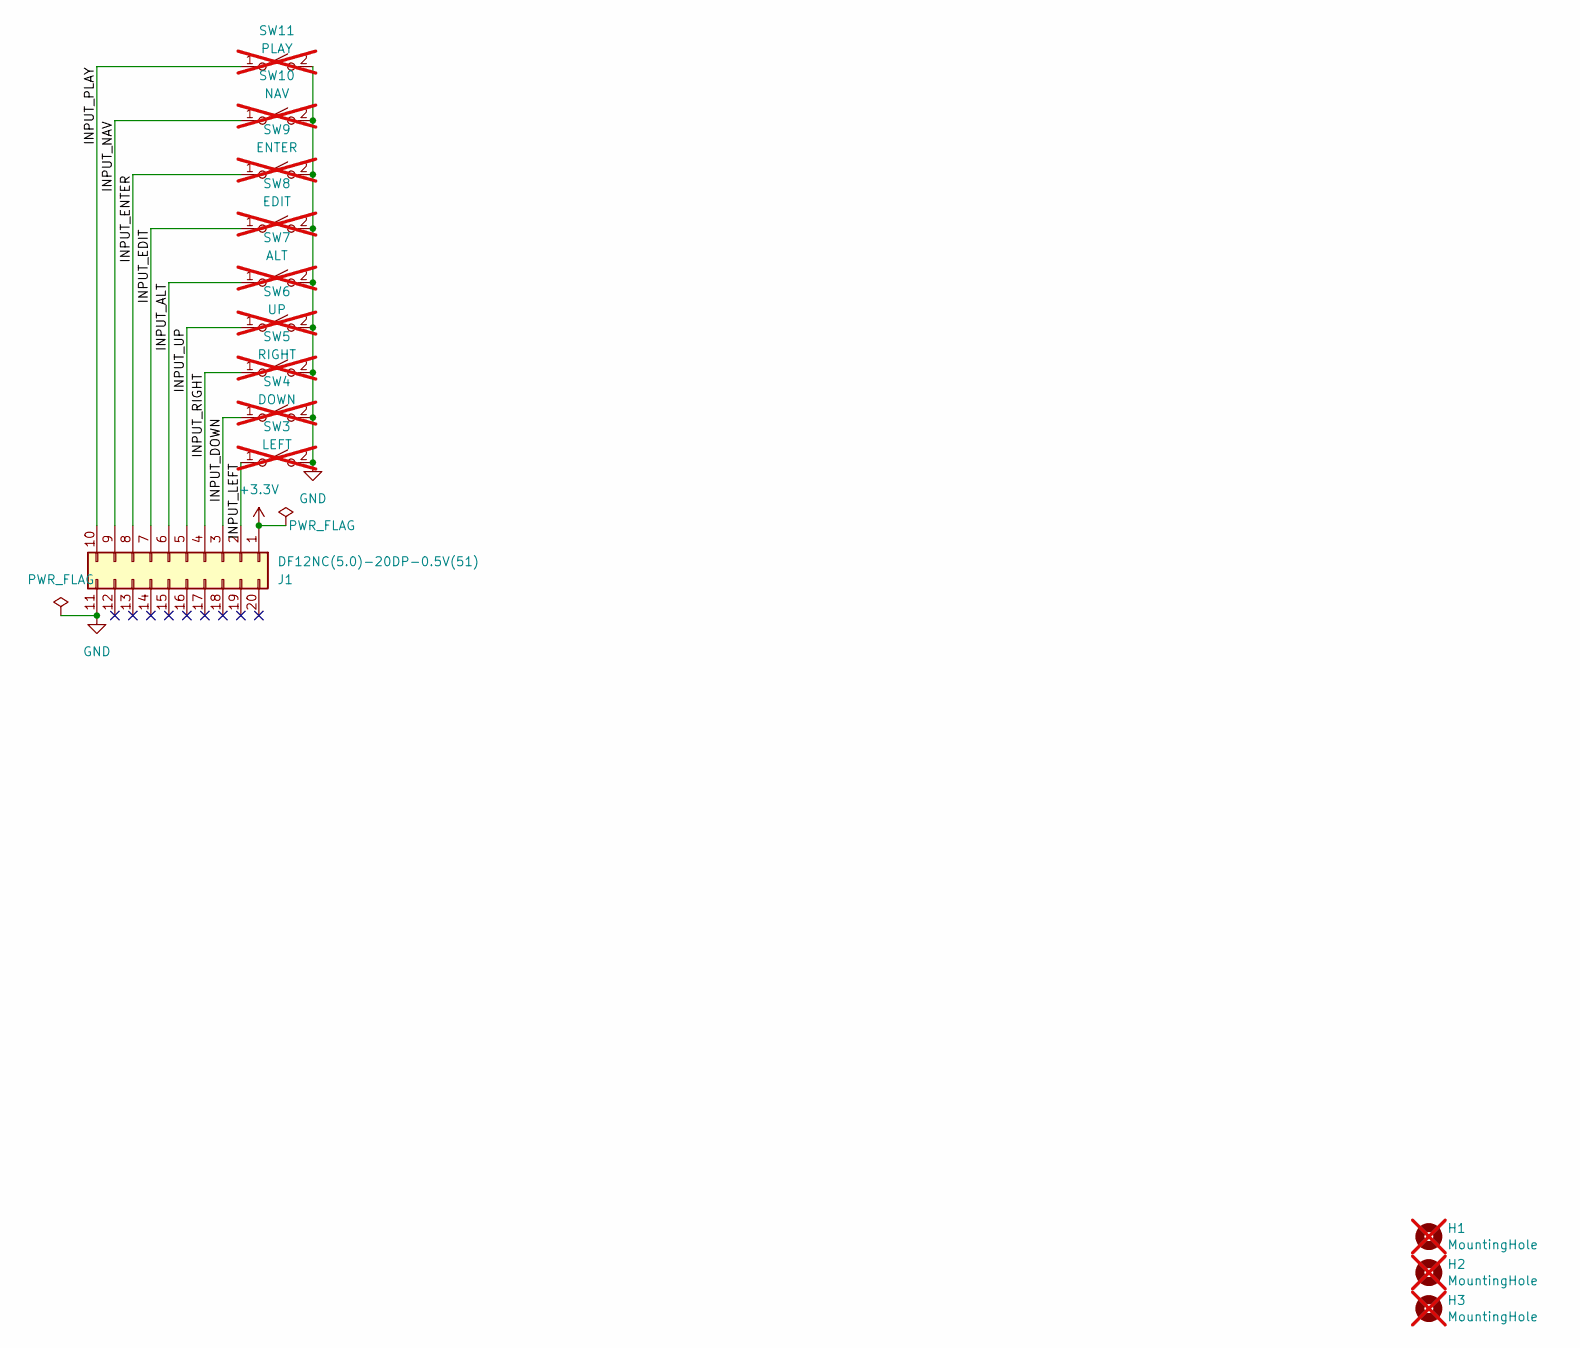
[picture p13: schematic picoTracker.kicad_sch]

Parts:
H1, H2, H3: MountingHole; MountingHole_3.2mm_M3; not fitted
J1: DF12NC(5.0)-20DP-0.5V(51); Hirose_DF12_DF12E3.0-20DP-0.5V_2x10_P0.50mm_Vertical; LCSC C3650665
SW3: LEFT; Cherry-MX-Low-Profile-kailh; LCSC C400229; not fitted
SW4: DOWN; Cherry-MX-Low-Profile-kailh; LCSC C400229; not fitted
SW5: RIGHT; Cherry-MX-Low-Profile-kailh; LCSC C400229; not fitted
SW6: UP; Cherry-MX-Low-Profile-kailh; LCSC C400229; not fitted
SW7: ALT; Cherry-MX-Low-Profile-kailh; LCSC C400229; not fitted
SW8: EDIT; Cherry-MX-Low-Profile-kailh; LCSC C400229; not fitted
SW9: ENTER; Cherry-MX-Low-Profile-kailh; LCSC C400229; not fitted
SW10: NAV; Cherry-MX-Low-Profile-kailh; LCSC C400229; not fitted
SW11: PLAY; Cherry-MX-Low-Profile-kailh; LCSC C400229; not fitted

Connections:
+3.3V: J1.1
/INPUT_ALT: J1.6, SW7.1 (A)
/INPUT_DOWN: J1.3, SW4.1 (A)
/INPUT_EDIT: J1.7, SW8.1 (A)
/INPUT_ENTER: J1.8, SW9.1 (A)
/INPUT_LEFT: J1.2, SW3.1 (A)
/INPUT_NAV: J1.9, SW10.1 (A)
/INPUT_PLAY: J1.10, SW11.1 (A)
/INPUT_RIGHT: J1.4, SW5.1 (A)
/INPUT_UP: J1.5, SW6.1 (A)
GND: J1.11, SW3.2 (B), SW4.2 (B), SW5.2 (B), SW6.2 (B), SW7.2 (B), SW8.2 (B), SW9.2 (B), SW10.2 (B), SW11.2 (B)

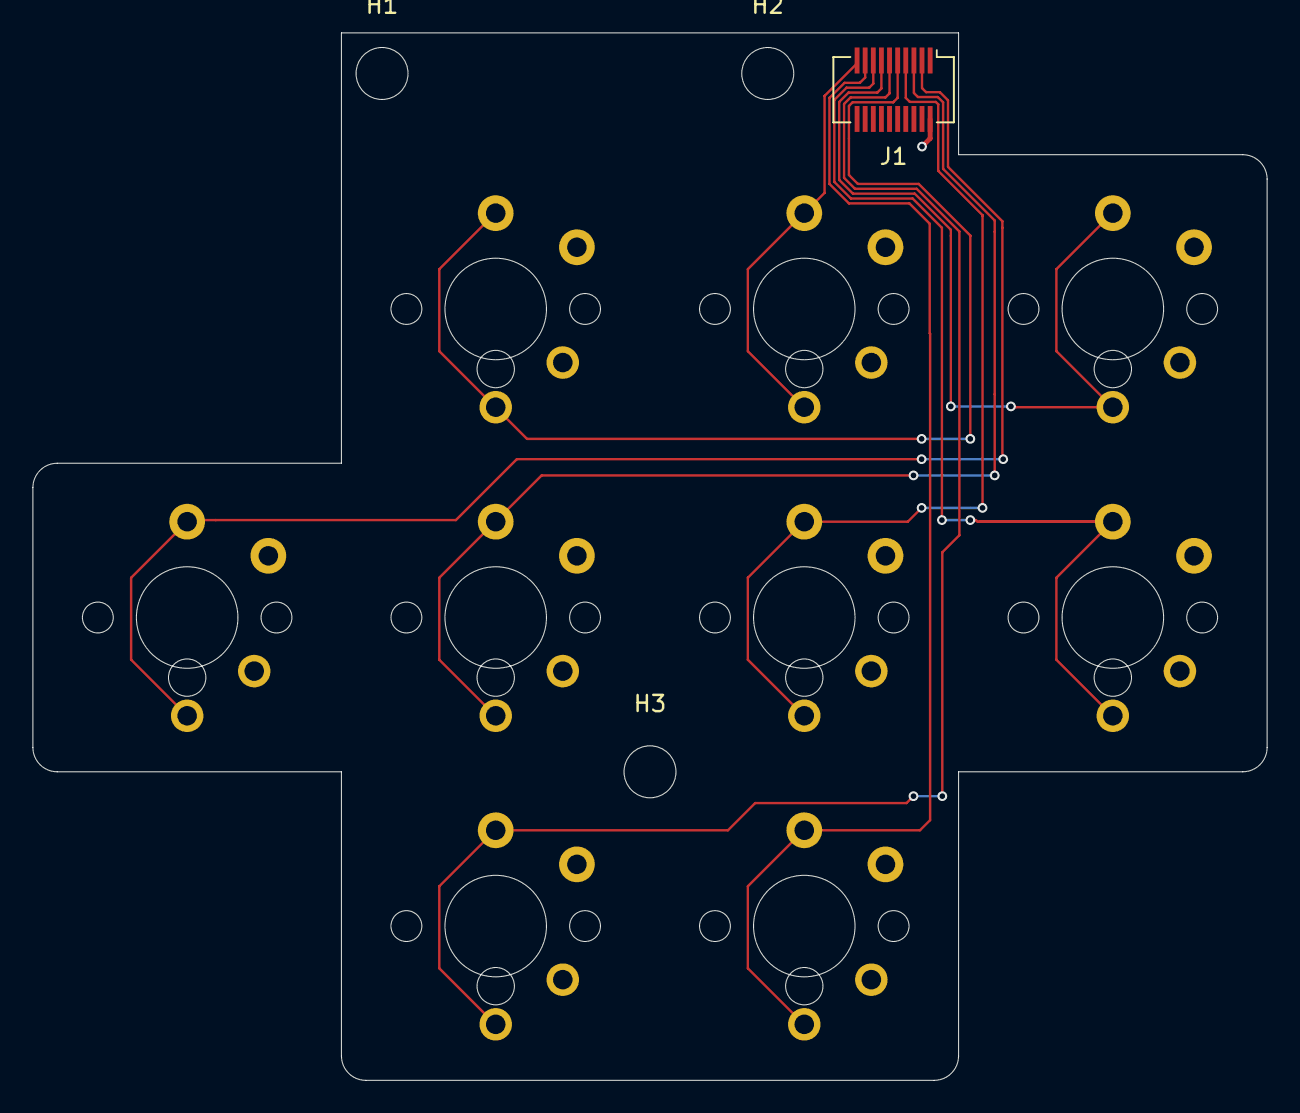
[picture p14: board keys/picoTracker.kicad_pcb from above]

Board: 2 copper layers, 76.0 x 64.5 mm, 13 parts (0 on the bottom side), 10 nets.

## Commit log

2025-03-28 picoTracker PCB v2.1 and picoTrackerKeypad PCB v2.0
    [DF12NC(5.0)-20DP.stp, DF12NC-20DS.stp, QFN-16 (3x3).stp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]
2025-03-28 updated pcb render
2025-03-28 Added bezel v2.0
    [bezel.kicad_pcb, bezel.kicad_sch, designators.csv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]
